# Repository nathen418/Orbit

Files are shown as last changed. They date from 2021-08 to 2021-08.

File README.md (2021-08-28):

# Orbit

# What happened here?
Old design files for an Arduino based clock I was building. Most stuff here is not mine, I was going to modify the files. Lost all of my work. This repo exists only so that I may return to the project at a later date. At the moment I have no energy or will to continue working on it as months of work has been lost. I got as far as fully working code and fully working hardware. I had the pcb's printed and soldered everything onto them. They worked perfectly. I still have all of the 8 revisions to the hardware. MONTHS of work gone, so 🤷‍♂️ I don't know what I am going to do. If I do return to the project, I will have to start from scratch, and will probably choose a Raspberry Pi Pico as the microcontroller, but I really have no idea.

Maybe in the future I will find a backup of the files and return to the project, however this seems unlikely.

Toodles.

## Questions?
- **Contact me on discord at nathen418#0002 or join my discord server at the link below**

## Modifications
- no issues will be resolved
- no pull requests wil be merged
- no comments on files will be answered.
- If you have a question, contact me through my discord

## Join my discord server:
https://dsc.gg/antaresnetwork

## License

- Im not a legal person so as long as I am credited in a somewhat obvious location, by my name or a link to this repository, I'm ok with it. If my name is not at the top of the file in a comment, it was not written by me and is only in this repo to serve as an example of something I was using for help. If my name does not appear on the file in a comment at the top, than it is not my code, it is class material.  If you have a problem with any of this, refer to my discord server and dm me.

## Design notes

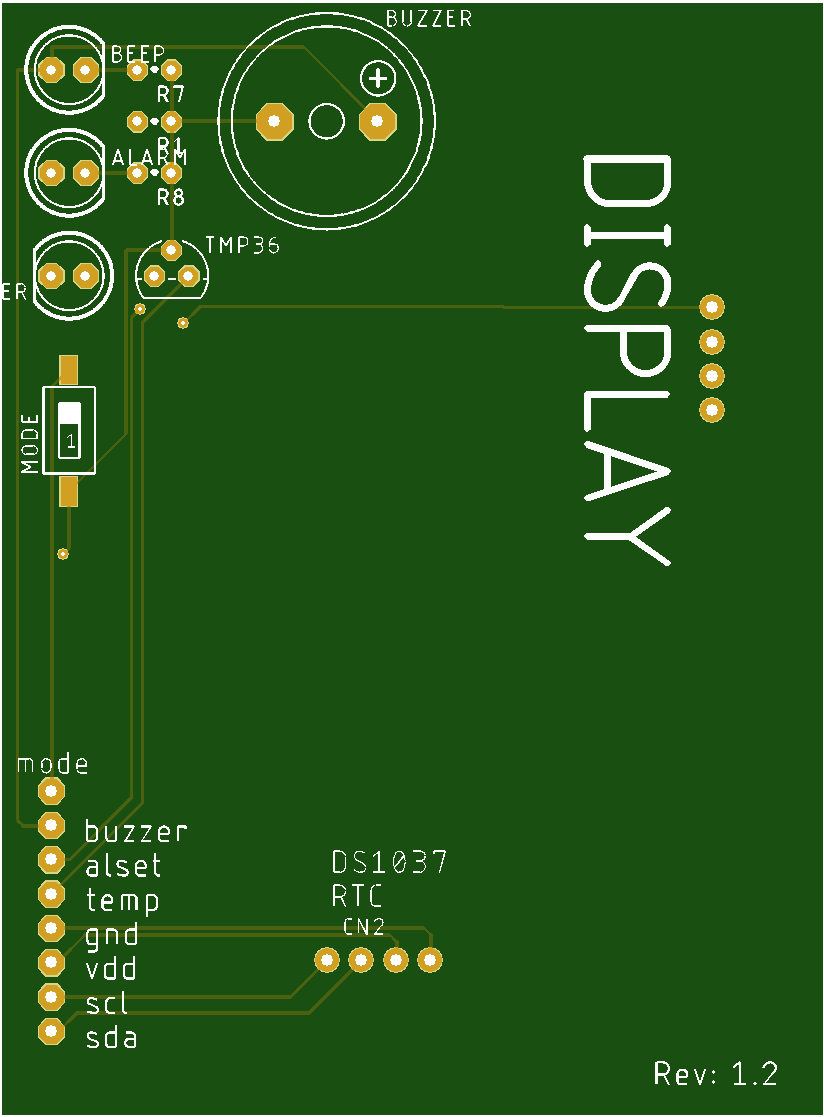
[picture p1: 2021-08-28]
downImg1.png

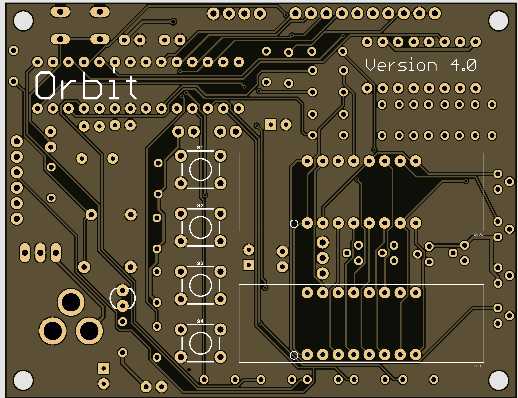
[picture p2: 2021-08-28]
Screenshot 2021-08-27 213251.png

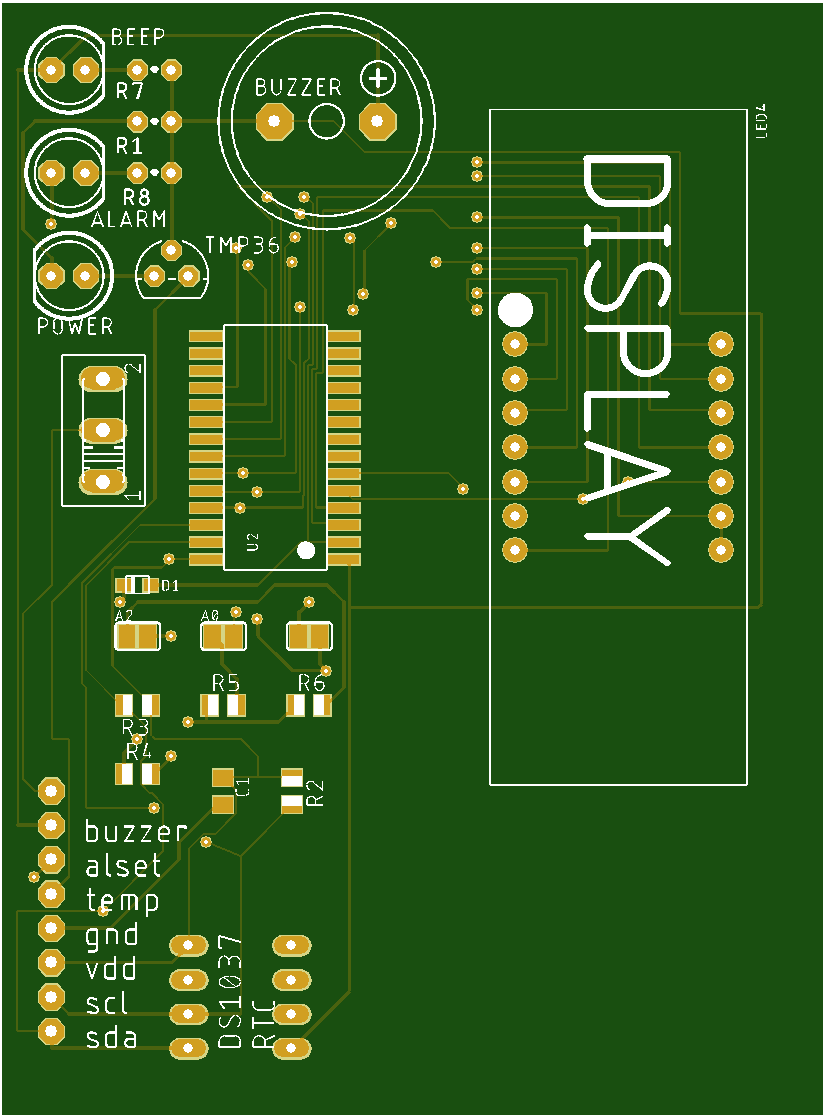
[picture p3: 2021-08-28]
downImg2.png

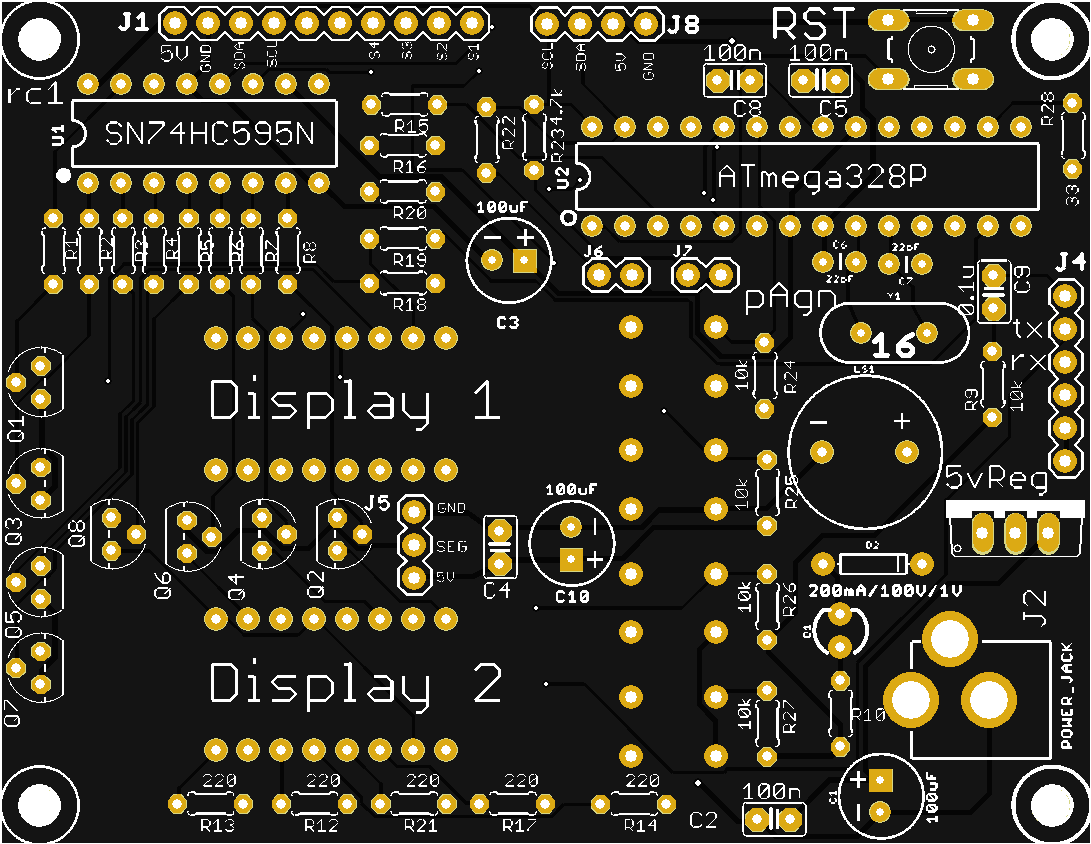
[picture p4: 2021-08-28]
downImg.png

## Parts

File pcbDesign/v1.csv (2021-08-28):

Qty | Value | Device | Package | Parts | Description
1 |  | 10-XX | B3F-10XX | RST | OMRON SWITCH
8 |  | 2N3906 | TO92 | Q1, Q2, Q3, Q4, Q5, Q6, Q7, Q8 | PNP Transistor
1 |  | 47346-0001 | MOLEX_47346-0001 | J3 | CONN RCPT 5POS MICRO USB R/A SMD
1 |  | 6_PIN_SERIAL_TARGET | 1X06 | J4 | 6-pin header connection for use with the FTDI BASIC" pinout - TARGET SIDE."
2 |  | CONN_02 | 1X02 | J6, J7 | Multi connection point. Often used as Generic Header-pin footprint for 0.1 inch spaced/style header connections
1 |  | CONN_03 | 1X03 | J5 | Multi connection point. Often used as Generic Header-pin footprint for 0.1 inch spaced/style header connections
1 |  | CONN_10";1X10" | J1 | Multi connection point. Often used as Generic Header-pin footprint for 0.1 inch spaced/style header connections
1 |  | I2C_STANDARD | 1X04 | J8 | SparkFun I2C Standard Pinout Header
1 |  | LED3MM | LED_3MM | D1 | LED (Generic)
4 |  | MOMENTARY-SWITCH-SPST-PTH-6.0MM | TACTILE_SWITCH_PTH_6.0MM | S1, S2, S3, S4 | Momentary Switch (Pushbutton) - SPST
1 | 0.1u | C-US025-025X050 | C025-025X050 | C9 | CAPACITOR, American symbol
4 | 100n | C-US025-025X050 | C025-025X050 | C2, C4, C5, C8 | CAPACITOR, American symbol
3 | 100uF | 100UF-POLAR-RADIAL-2.5MM-25V-20% | CPOL-RADIAL-2.5MM-6.5MM | C1, C3, C10 | 100µF polarized capacitors
5 | 10k | R-US_0204/5 | 0204/5 | R9, R24, R25, R26, R27 | RESISTOR, American symbol
1 | 16MHz | CRYSTAL-16MHZPTH-HC49US | HC49US | Y1 | 16MHz Crystal
1 | 1k | R-US_0204/5 | 0204/5 | R10 | RESISTOR, American symbol
1 | 200mA/100V/1V | DIODE-1N4148 | DIODE-1N4148 | D2 | Diode
10 | 220 | R-US_0204/5 | 0204/5 | R12, R13, R14, R15, R16, R17, R18, R19, R20, R21 | RESISTOR, American symbol
2 | 22pF | 22PF-PTH-2.54MM-200V-5% | CAP-PTH-2.54 | C6, C7 | 22pF ceramic capacitors
1 | 328P | ATMEGA328P_PDIP | DIP28 | U2 | Atmel 328P
1 | 33 | R-US_0204/5 | 0204/5 | R28 | RESISTOR, American symbol
8 | 330 | R-US_0204/5 | 0204/5 | R1, R2, R3, R4, R5, R6, R7, R8 | RESISTOR, American symbol
2 | 4.7k | R-US_0204/5 | 0204/5 | R22, R23 | RESISTOR, American symbol
1 | BUZZER-PTH | BUZZER-PTH | BUZZER-12MM | LS1 | Buzzer
1 | POWER_JACK | POWER_JACK | POWER_JACK_PTH | J2 | Power Jack Connector
1 | SN74HC595N | 74HC595N | DIP16 | U1 | 8-Bit Shift Register (Serial to Parallel)
2 | YSD-439AB4B-35 | 7-SEGMENT-4DIGIT-10MM-BLUE | 7-SEGMENT-4DIGIT-YOUNGSUN | LED1, LED2 | 4 Digit 7 Segment Display

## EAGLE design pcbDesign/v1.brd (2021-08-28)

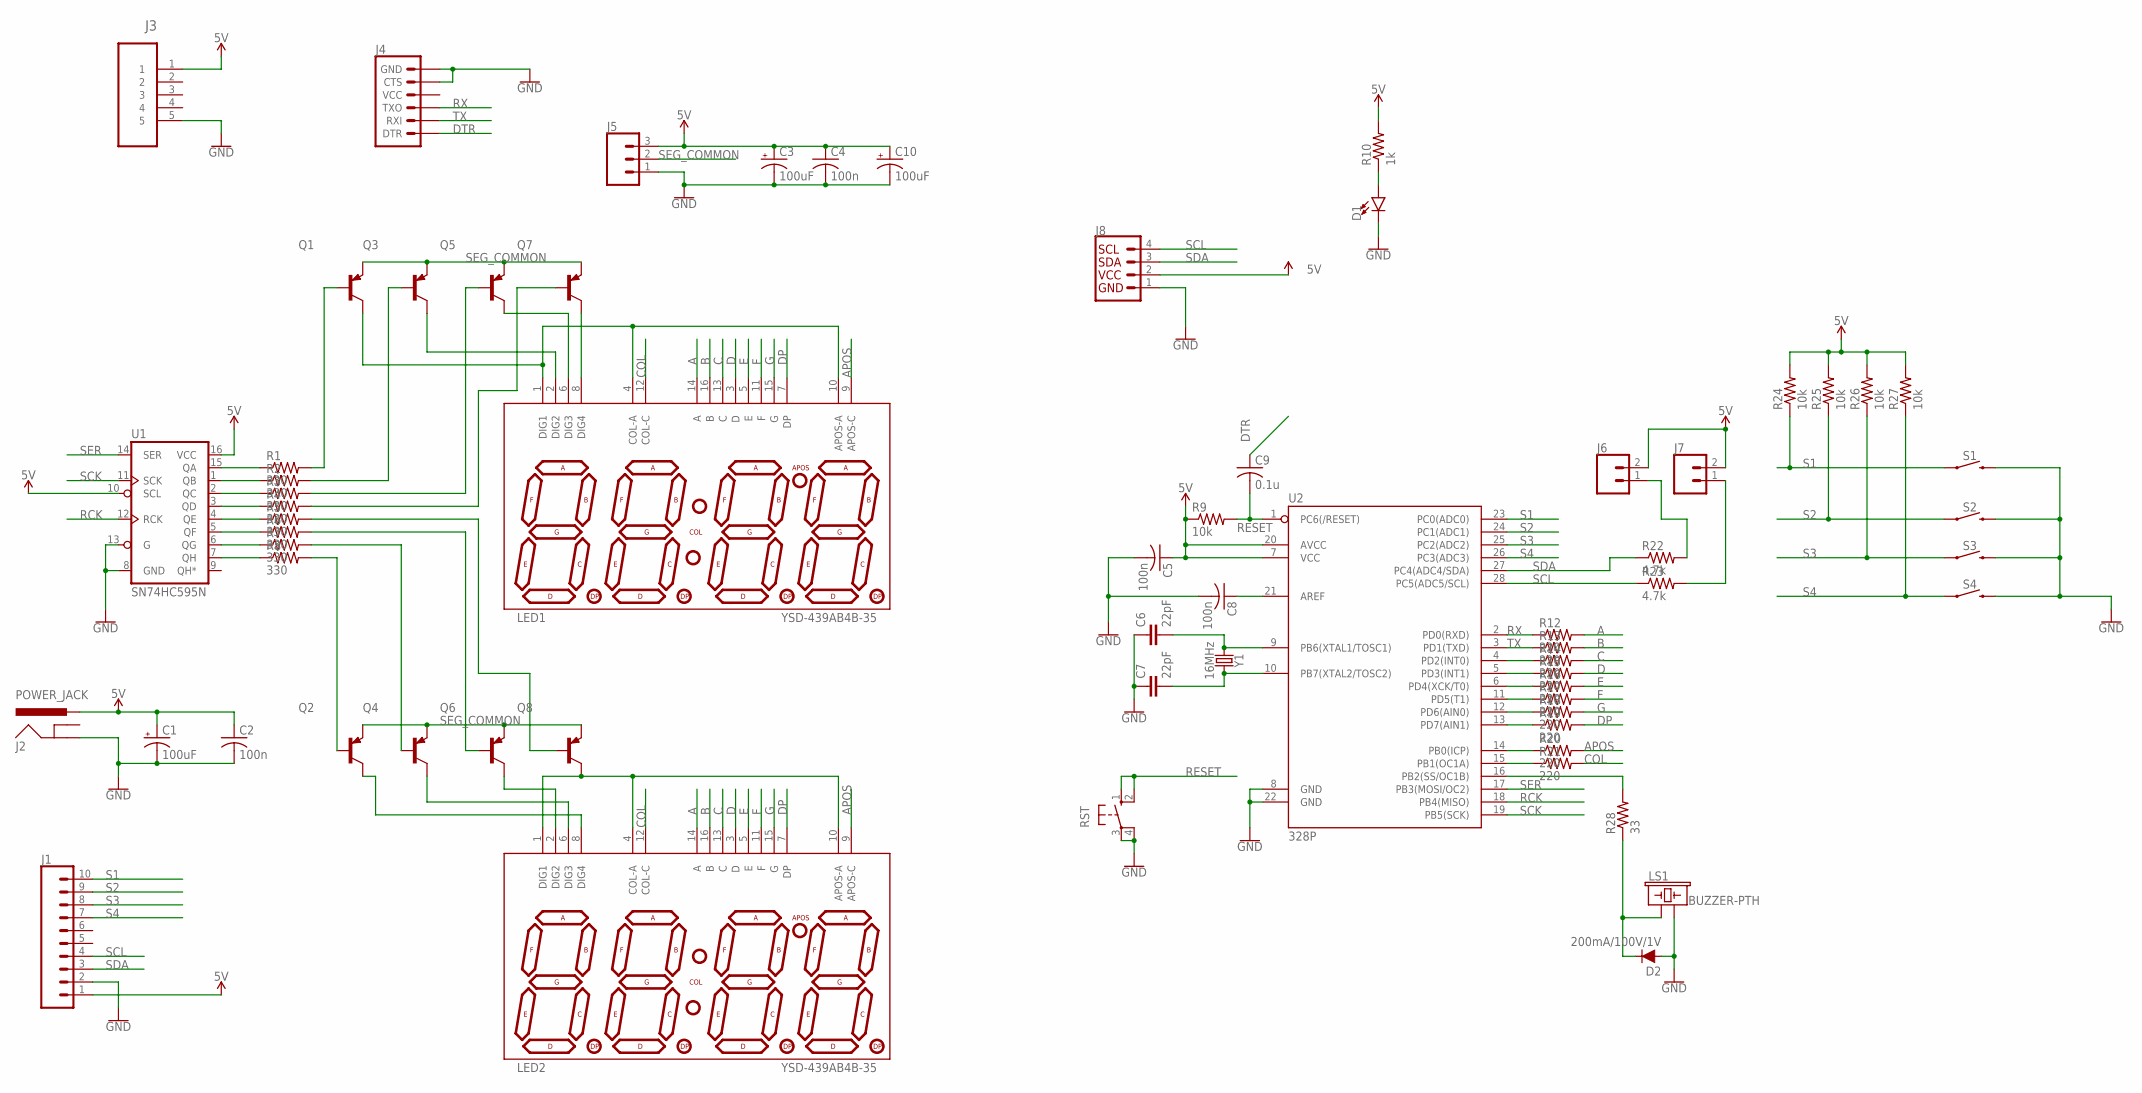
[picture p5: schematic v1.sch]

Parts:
C1, C3, C10: 100uF; CPOL-RADIAL-2.5MM-6.5MM
C2, C4, C5, C8: 100n; C025-025X050
C6, C7: 22pF; CAP-PTH-2.54
C9: 0.1u; C025-025X050
D1: LED3MM; LED_3MM
D2: 200mA/100V/1V; DIODE-1N4148
J1: CONN_10"; 1X10
J2: POWER_JACK; POWER_JACK_PTH
J3: 47346-0001; MOLEX_47346-0001
J4: 6_PIN_SERIAL_TARGET; 1X06
J5: CONN_03; 1X03
J6, J7: CONN_02; 1X02
J8: I2C_STANDARD; 1X04
LED1, LED2: YSD-439AB4B-35; 7-SEGMENT-4DIGIT-YOUNGSUN
LS1: BUZZER-PTH; BUZZER-12MM
Q1, Q2, Q3, Q4, Q5, Q6, Q7, Q8: 2N3906; TO92
R1, R2, R3, R4, R5, R6, R7, R8: 330; 0204/5
R9, R24, R25, R26, R27: 10k; 0204/5
R10: 1k; 0204/5
R12, R13, R14, R15, R16, R17, R18, R19, R20, R21: 220; 0204/5
R22, R23: 4.7k; 0204/5
R28: 33; 0204/5
RST: 10-XX; B3F-10XX
S1, S2, S3, S4: MOMENTARY-SWITCH-SPST-PTH-6.0MM; TACTILE_SWITCH_PTH_6.0MM
U1: SN74HC595N; DIP16
U2: 328P; DIP28
Y1: 16MHz; HC49US

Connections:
5V: C1.1 (+), C2.1, C3.1 (+), C4.1, C5.1, C10.1 (+), J1.1, J2.PWR, J3.1, J5.3, J6.2, J7.2, J8.2, R9.1, R10.2, R24.2, R25.2, R26.2, R27.2, U1.10 (SCL), U1.16 (VCC), U2.7 (VCC), U2.20 (AVCC)
A: LED1.14 (A), LED2.14 (A), R12.2
APOS: LED1.9 (APOS-C), LED2.9 (APOS-C), R20.2
B: LED1.16 (B), LED2.16 (B), R13.2
C: LED1.13 (C), LED2.13 (C), R14.2
COL: LED1.12 (COL-C), LED2.12 (COL-C), R21.2
D: LED1.3 (D), LED2.3 (D), R15.2
DP: LED1.7 (DP), LED2.7 (DP), R19.2
DTR: C9.1, J4.1 (DTR)
E: LED1.5 (E), LED2.5 (E), R16.2
F: LED1.11 (F), LED2.11 (F), R17.2
G: LED1.15 (G), LED2.15 (G), R18.2
GND: C1.2 (-), C2.2, C3.2 (-), C4.2, C5.2, C6.1, C7.1, C8.2, C10.2 (-), D1.K (C), D2.A, J1.2, J2.GND, J3.5, J4.5 (CTS), J4.6 (GND), J5.1, J8.1, LS1.- (2), RST.3, RST.4 (P1), S1.3 (2), S2.3 (2), S3.3 (2), S4.3 (2), U1.8 (GND), U1.13 (G), U2.8 (GND), U2.22 (GND)
unnamed: D1.A, R10.1
unnamed: R21.1, U2.15 (PB1(OC1A))
unnamed: R14.1, U2.4 (PD2(INT0))
unnamed: R15.1, U2.5 (PD3(INT1))
unnamed: R16.1, U2.6 (PD4(XCK/T0))
unnamed: R17.1, U2.11 (PD5(T1))
unnamed: R18.1, U2.12 (PD6(AIN0))
unnamed: R19.1, U2.13 (PD7(AIN1))
unnamed: C6.2, U2.9 (PB6(XTAL1/TOSC1)), Y1.1
unnamed: C7.2, U2.10 (PB7(XTAL2/TOSC2)), Y1.2
unnamed: LED1.1 (DIG1), LED1.4 (COL-A), LED1.10 (APOS-A), Q1.1 (C)
unnamed: LED1.6 (DIG3), Q5.1 (C)
unnamed: LED1.2 (DIG2), Q3.1 (C)
unnamed: R28.2, U2.16 (PB2(SS/OC1B))
unnamed: LED2.1 (DIG1), LED2.4 (COL-A), LED2.10 (APOS-A), Q8.1 (C)
unnamed: D2.C, LS1.+ (1), R28.1
unnamed: LED2.2 (DIG2), Q6.1 (C)
unnamed: LED2.6 (DIG3), Q4.1 (C)
unnamed: LED2.8 (DIG4), Q2.1 (C)
unnamed: LED1.8 (DIG4), Q7.1 (C)
unnamed: Q1.2 (B), R1.2
unnamed: Q3.2 (B), R2.2
unnamed: Q5.2 (B), R3.2
unnamed: Q7.2 (B), R4.2
unnamed: Q8.2 (B), R5.2
unnamed: Q6.2 (B), R6.2
unnamed: Q4.2 (B), R7.2
unnamed: Q2.2 (B), R8.2
unnamed: R1.1, U1.15 (QA)
unnamed: R2.1, U1.1 (QB)
unnamed: R3.1, U1.2 (QC)
unnamed: R4.1, U1.3 (QD)
unnamed: R5.1, U1.4 (QE)
unnamed: R6.1, U1.5 (QF)
unnamed: R7.1, U1.6 (QG)
unnamed: R8.1, U1.7 (QH)
unnamed: C8.1, U2.21 (AREF)
unnamed: J6.1, R22.2
unnamed: J7.1, R23.2
unnamed: R20.1, U2.14 (PB0(ICP))
RCK: U1.12 (RCK), U2.18 (PB4(MISO))
RESET: C9.2, R9.2, RST.1 (S), RST.2 (S1), U2.1 (PC6(/RESET))
RX: J4.3 (TXO), R12.1, U2.2 (PD0(RXD))
S1: J1.10, R24.1, S1.1, U2.23 (PC0(ADC0))
S2: J1.9, R25.1, S2.1, U2.24 (PC1(ADC1))
S3: J1.8, R26.1, S3.1, U2.25 (PC2(ADC2))
S4: J1.7, R27.1, S4.1, U2.26 (PC3(ADC3))
SCK: U1.11 (SCK), U2.19 (PB5(SCK))
SCL: J1.4, J8.4, R23.1, U2.28 (PC5(ADC5/SCL))
SDA: J1.3, J8.3, R22.1, U2.27 (PC4(ADC4/SDA))
SEG_COMMON: J5.2, Q1.3 (E), Q2.3 (E), Q3.3 (E), Q4.3 (E), Q5.3 (E), Q6.3 (E), Q7.3 (E), Q8.3 (E)
SER: U1.14 (SER), U2.17 (PB3(MOSI/OC2))
TX: J4.2 (RXI), R13.1, U2.3 (PD1(TXD))

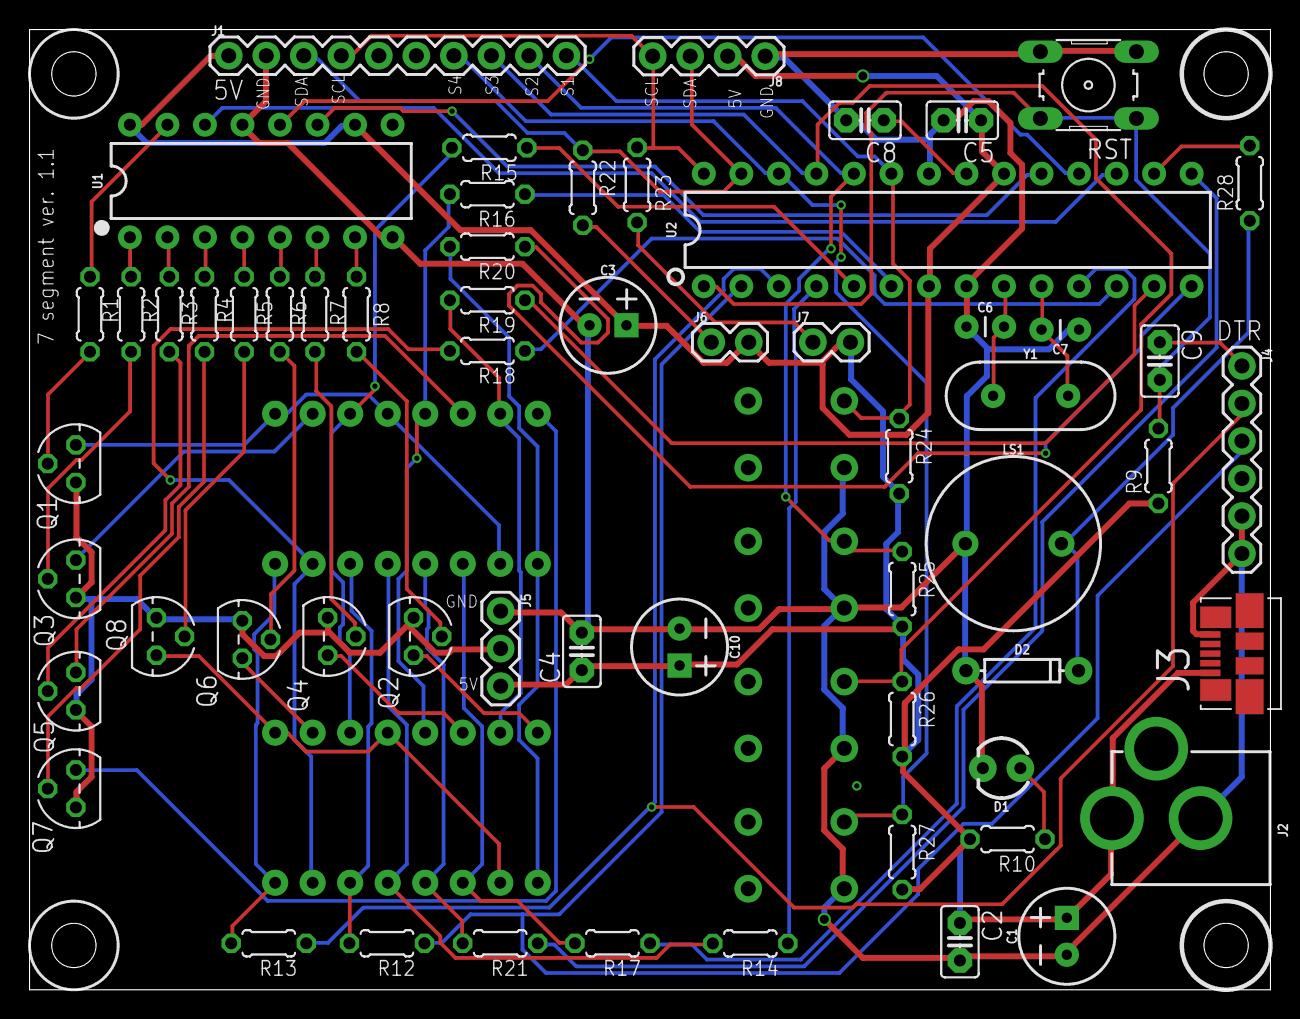
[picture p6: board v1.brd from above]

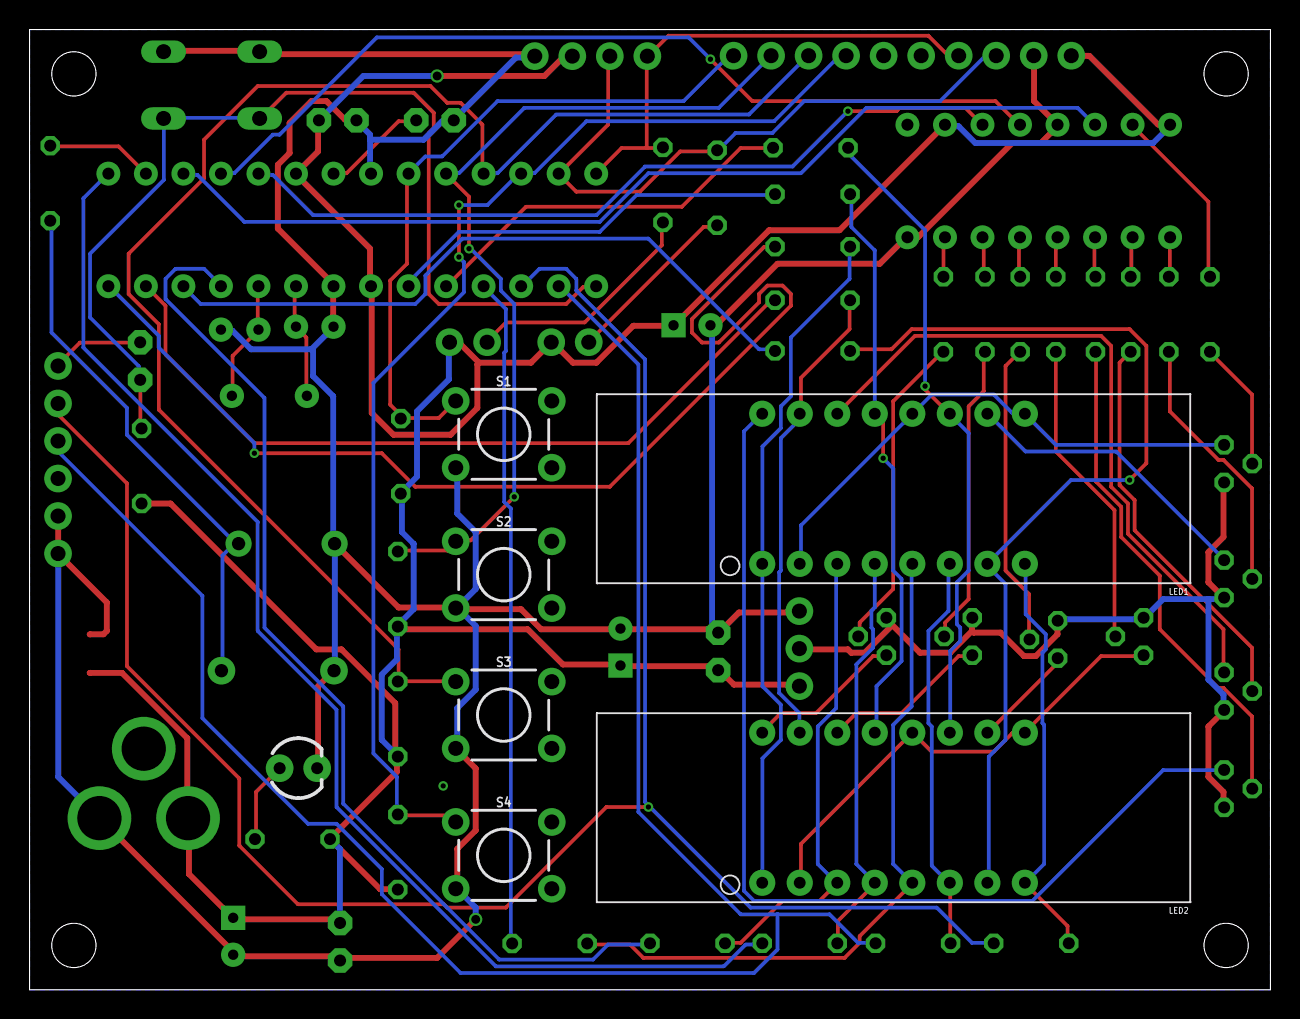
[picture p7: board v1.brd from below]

Board: 2 copper layers, 84.0 x 65.0 mm, 66 parts (6 on the bottom side), 66 nets.

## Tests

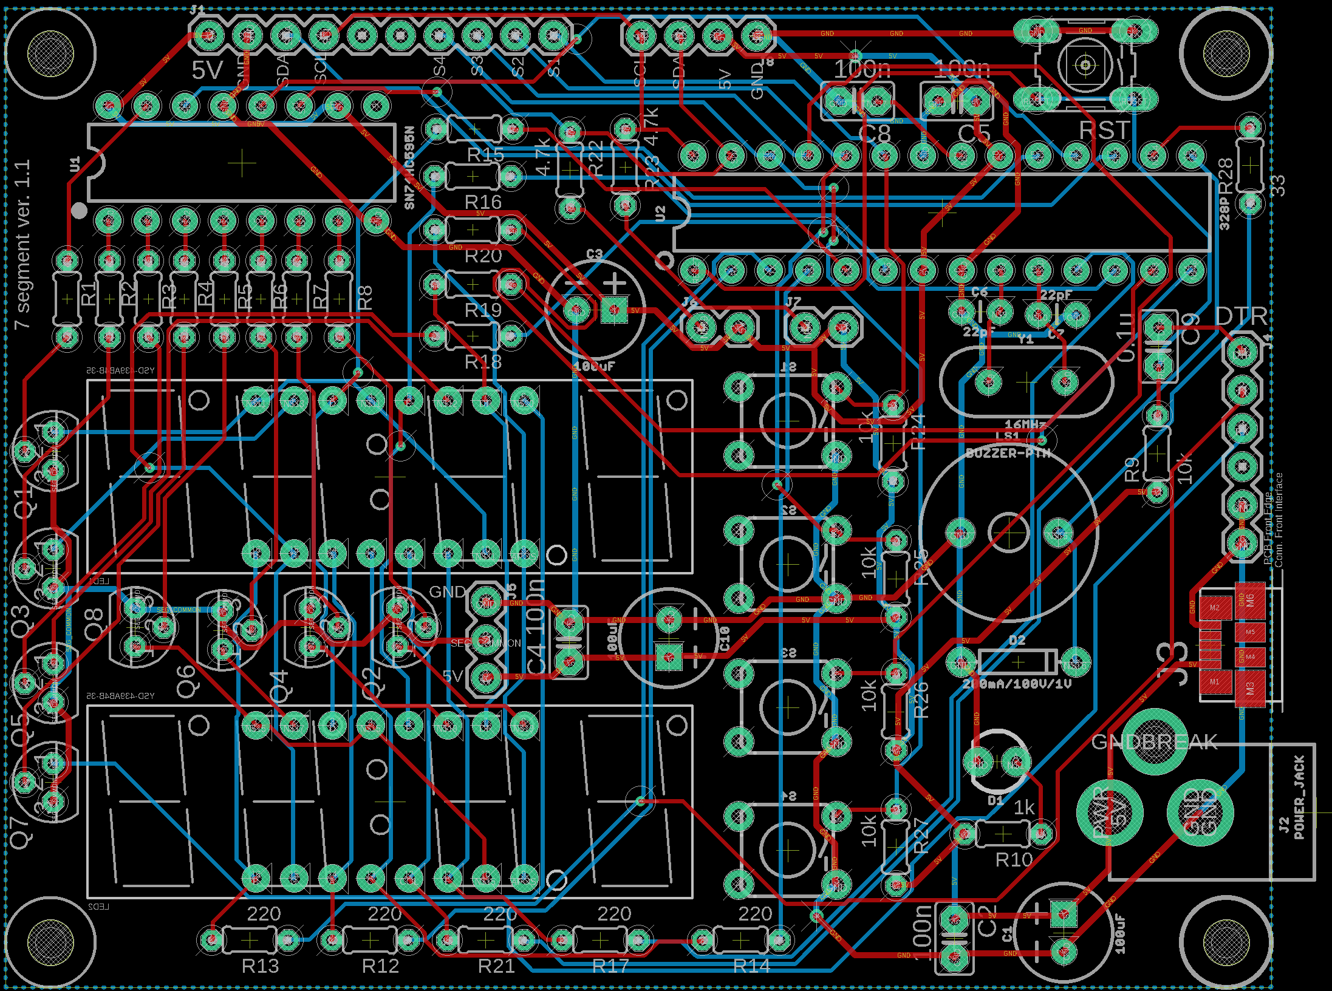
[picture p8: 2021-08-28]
pcbDesign/testshot2.png

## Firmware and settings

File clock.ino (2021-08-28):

//Global libraries
#include <TimeLib.h>  
#include <Wire.h>
#include <RTClib.h>
#include <PinChangeInterrupt.h>
//Local libraries
#include "sevenseg_display_drv.h"

//Define section
#define BUTTON_PLUS 12
#define BUTTON_MINUS 11
#define BUTTON_MODE 10
#define BUTTON_SET 13
#define MAX_MODE 2
#define SECS_PER_HOUR 3600


//Top variables
sevenseg_display_drv display7seg;
double light;
volatile uint8_t mode,stopwatch_running,mode_button_pressed;
volatile unsigned long last_time_button_falling,last_time_button_rising,elapsed_millisec,stopwatch_start_millisec;
//unsigned long 

RTC_DS3231 rtc;

void loop(){
	switch (mode) {
		case 0:
			mode=1;
			display7seg.clear_all();
			display7seg.set_dp_bottom(2);
			break;
		case 1://Clock with date
			show_clock_up();
			show_date_down();
			set_brightness();
			break;
		case 10://Clock with year
			display7seg.clear_all();
			mode=11;
			break;
		case 11://Clock with year
			show_clock_up();
			show_year_down();
			set_brightness();
			break;
		case 20://Stop watch
			mode=21;
			display7seg.clear_all();
			display7seg.set_colon_top();
			display7seg.set_dp_bottom(2);
			break;
		case 21://Stop watch
			stopwatch();
			break;
		default:
			mode=0;
			break;
	}//switch
}

void stopwatch(){
	//Stopwatch function	
	if(stopwatch_running==1) elapsed_millisec=millis()-stopwatch_start_millisec;
	
	uint16_t total_sec=elapsed_millisec/1000;
	uint16_t delata_millisec=elapsed_millisec%1000;
	uint8_t delta_sec=total_sec%60;
	uint8_t delta_min=total_sec/60%60;
	uint8_t delta_hour=total_sec/60/60;
	
	uint8_t digit;
	digit=elapsed_millisec/10%10;
	display7seg.set_digit_bottom(0, digit);
	digit=elapsed_millisec/100%10;
	display7seg.set_digit_bottom(1, digit);
	digit=delta_sec%10;
	display7seg.set_digit_bottom(2, digit);
	digit=delta_sec/10;
	display7seg.set_digit_bottom(3, digit);
	
	digit=delta_min%10;
	display7seg.set_digit_top(0, digit);
	digit=delta_min/10;
	display7seg.set_digit_top(1, digit);
	digit=delta_hour%10;
	display7seg.set_digit_top(2, digit);
	digit=delta_hour/10;
	display7seg.set_digit_top(3, digit);
}

void set_brightness(){
	light = 0;
	for (int i = 0; i < 2000; i++) {
		light += analogRead(A3);
	}

	light = int((light/ 2000) / 1024 * 15);
	display7seg.set_brightness(light);
}

void show_clock_up(){
	display7seg.set_digit_top(0, minute()%10);
	display7seg.set_digit_top(1, minute()/10);
	display7seg.set_digit_top(2, hour()%10);
	display7seg.set_digit_top(3, hour()/10);
	
	if (millis()%1000 > 500) display7seg.set_colon_top();
	else display7seg.reset_colon_top();
}

void show_date_down(){
	display7seg.set_digit_bottom(0, month()%10);
	display7seg.set_digit_bottom(1, month()/10);
	display7seg.set_digit_bottom(2, day()%10);
	display7seg.set_digit_bottom(3, day()/10);
}

void show_year_down(){
	uint8_t digit;
	
	digit=year()%10;
	display7seg.set_digit_bottom(0, digit);
	digit=year()/10%10;
	display7seg.set_digit_bottom(1, digit);
	digit=year()/100%10;
	display7seg.set_digit_bottom(2, digit);
	digit=year()/1000%10;
	display7seg.set_digit_bottom(3, digit);
}

void print_float_num_bottom(double floatnum) {
	char tempString[5];
	int fourdigits;

	display7seg.reset_dp_bottom(0);
	display7seg.reset_dp_bottom(1);
	display7seg.reset_dp_bottom(2);
	display7seg.reset_dp_bottom(3);
	
	int dig_num = log10(floatnum) + 1;
	if (dig_num >= 0) {
		fourdigits = round(floatnum*pow(10, 4 - dig_num));
		if (fourdigits==0) sprintf(tempString, "%4s", "0000");
		else sprintf(tempString, "%4d", fourdigits);
		display7seg.set_digit_bottom(0, (uint8_t)(tempString[3] - '0'));
		display7seg.set_digit_bottom(1, (uint8_t)(tempString[2] - '0'));
		display7seg.set_digit_bottom(2, (uint8_t)(tempString[1] - '0'));
		display7seg.set_digit_bottom(3, (uint8_t)(tempString[0] - '0'));
		display7seg.set_dp_bottom(4 - dig_num);
	}
	else {
		fourdigits = round(floatnum*10000);
		sprintf(tempString, "%4d", fourdigits);
		display7seg.set_digit_bottom(0, fourdigits % 10 );
		display7seg.set_digit_bottom(1, fourdigits /10 %10);
		display7seg.set_digit_bottom(2, (fourdigits /100 % 10));
		display7seg.set_digit_bottom(3, 0);
		display7seg.set_dp_bottom(3);
	}
}

//http://forum.arduino.cc/index.php?topic=44262.0
char *ftoa(char *a, double f, int precision)
{
	long p[] = { 0,10,100,1000,10000,100000,1000000,10000000,100000000 };

	char *ret = a;
	long heiltal = (long)f;
	itoa(heiltal, a, 10);
	while (*a != '\0') a++;
	*a++ = '.';
	long desimal = abs((long)((f - heiltal) * p[precision]));
	itoa(desimal, a, 10);
	return ret;
}

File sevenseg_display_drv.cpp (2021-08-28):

#include "sevenseg_display_drv.h"

static sevenseg_display_drv *active7segment = NULL;

sevenseg_display_drv::sevenseg_display_drv() { }

void sevenseg_display_drv::begin_drv()
{
	//Start refreshing Nothing will be displayed before this function called
	//From http://www.instructables.com/id/Arduino-Timer-Interrupts/
	//Set timer1 - 16 bit timer
	
	cli();// disable global interrupts
	TCCR1A = 0;// set entire TCCR1A register to 0
	TCCR1B = 0;// same for TCCR1B
	TCNT1 = 0;//initialize counter value to 0

	//Prescaller (timer speed(Hz)) = (Arduino clock speed(16MHz)) / prescaler
	TCCR1B |= (1 << CS10); //No prescaller 63ns per count for 16MHz clock
	
	//Also notice how the setups between the three timers differ slightly in the line which turns on CTC mode :
	//TCCR0A |= (1 << WGM01);//for timer0
	//TCCR1B |= (1 << WGM12);//for timer1
	//TCCR2A |= (1 << WGM21);//for timer2
	TCCR1B |= (1 << WGM12);//CTC mode

	// OCR#A (the compare match value)
	//remember that when you use timers 0 and 2 this number must be less than 256, and less than 65536 for timer1
	OCR1A = 999;//intrupt will happen 63ns*[this value] 63usec for 999
	//OCR1A = 496;//31usec
	TIMSK1 |= (1 << OCIE1A); // enable timer compare interrupt
	sei();//allow interrupts
}

ISR(TIMER1_COMPA_vect) {//change the 1 to 0 for timer0 and 2 for timer2
	active7segment->updateDisplay();//Matrix refrshing function
}

uint8_t sevenseg_display_drv::init()
{
	//Initialisation
	DDRB |= B00000011;//Set pins 0,1 of port B as output
	DDRD |= B11111111;//Sets pins 0 to 7 of port D as outputs, segments control
	DDRC |= B00000111;//Set bits 0,1,2 of port C as output, connection to 74HC595N


	PORTB &= B11111100;//Turn off colon and apostrof
	PORTD =  B00000000;//Turn off all segments
	PORTC &= B11111000;//Shift register controls low
	
	//Clear all bits of shift register
	for (uint8_t n = 0; n < NUMOFDIGITS; n++) {
		PORTC |= B00000010;//Serial clock high
		PORTC &= B11111101;//Serial clock low
	}
	PORTC |= B00000100;//Latch shift register data

	active7segment = this; // For interrupt hander

	//Clear memory
	clear_all();

	//For pwm_count_max=15 each digit can be turn on up to 1ms out of 8 ms
	//So reftesh rate something like 125Hz
	//pwm_count_max = 15;//Number of brightness levels
	brightness = 15;//Default value of brightness

	//Initiate variables
	pwm_count = 0;
	digit_num = 0;
	return 0;
}

void sevenseg_display_drv::clear_all(){
	//Clear memory
	for (uint8_t n = 0; n < NUMOFDIGITS; n++) {
		dp_buffer[n] =   B00000000;//Reset decimal point buffer
		displaybuff[n] = B00000000;//Set all digits to off
		colon_and_ap[n]= B00000000;//Clean colon and apos
	}
}

void sevenseg_display_drv::clear_top(){
	//Clear memory
	for (uint8_t n = 4; n < NUMOFDIGITS; n++) {
		dp_buffer[n] =   B00000000;//Reset decimal point buffer
		displaybuff[n] = B00000000;//Set all digits to off
		colon_and_ap[n]= B00000000;//Clean colon and apos
	}
}

void sevenseg_display_drv::clear_bottom(){
	//Clear memory
	for (uint8_t n = 0; n < 4; n++) {
		dp_buffer[n] =   B00000000;//Reset decimal point buffer
		displaybuff[n] = B00000000;//Set all digits to off
		colon_and_ap[n]= B00000000;//Clean colon and apos
	}
}

void sevenseg_display_drv::updateDisplay()
{
	/*
	This function refreshing display. Called only from interupt
	*/
	
	//Debug
	//PORTC |= B00000001;//Turn off all digits

	if (pwm_count < PWMCOUNTMAX) {
		//For brightness=0 display will be on for 1 cycle
		if (pwm_count > brightness) {
			PORTB &= B11111100;//Turn off colon and apostrof
			PORTD =  B00000000;//Turn off all segments
		}
		pwm_count++;//PWM counter
	}
	else {//End of current pwm cycle
		//Here we need to update information of digit
		pwm_count = 0;//restart pwm counter
		//Turn off all
		PORTB &= B11111100;//Turn off colon and apostrof
		PORTD  = B00000000;//Turn off all segments

		if (digit_num < NUMOFDIGITS) {// Digits 1-7
			PORTC &= B11111000;//Shift register latch data and clock signal low
			PORTC |= B00000010;//Serial clock high
			PORTC |= B00000101;//Latch data, serial data to high
		}
		else {//Digit 0
			digit_num = 0;//First digit
			//Turn on first digit
			PORTC &= B11111001;//Shift register latch and clock signal low. Data already high vrom previous cycle
			PORTC |= B00000010;//Serial clock high
			PORTC |= B00000100;//Latch data
		}
		//Ser digit data
		PORTD = displaybuff[digit_num];//Apply data for segments of current digit
		PORTB |= colon_and_ap[digit_num];//Colon and apostrophe 
		digit_num++;//Next digit
	}//end else
	
	//*** Debug ***
	//long elapsed = micros() - time_start;
	//Serial.println(elapsed);
	//PORTC &= B11111110;//Turn off all digits
	//********************
}

//Set value of digit
void sevenseg_display_drv::set_digit( uint8_t dig_num, uint8_t value){
	if(dig_num<0 || dig_num>(NUMOFDIGITS-1)) return;
	displaybuff[dig_num]=pgm_read_byte_near(&bcd[value])|dp_buffer[dig_num];
}

void sevenseg_display_drv::set_digit_top( uint8_t dig_num, uint8_t value){
	set_digit( dig_num+4, value);
}

void sevenseg_display_drv::set_digit_bottom( uint8_t dig_num, uint8_t value){
	set_digit( 3-dig_num, value);
}

//Set brightness of all digits
void sevenseg_display_drv::set_brightness(uint8_t value) {
	if (value<= PWMCOUNTMAX) brightness = value;
	else brightness = PWMCOUNTMAX;
}


void sevenseg_display_drv::set_dp_top(uint8_t dig_num) {
	if(dig_num<0 || dig_num>(NUMOFDIGITS-1)) return;
	dp_buffer[dig_num+4] = B10000000;
	displaybuff[dig_num+4] |= dp_buffer[dig_num+4];
}

void sevenseg_display_drv::set_dp_bottom(uint8_t dig_num) {
	if(dig_num<0 || dig_num>(NUMOFDIGITS-1)) return;
	dp_buffer[3-dig_num] = B10000000;
	displaybuff[3-dig_num] |= dp_buffer[3-dig_num];
}

void sevenseg_display_drv::reset_dp_top(uint8_t dig_num) {
	if(dig_num<0 || dig_num>(NUMOFDIGITS-1)) return;
	dp_buffer[dig_num] = B00000000;
	displaybuff[dig_num] &= B01111111;
}

void sevenseg_display_drv::reset_dp_bottom(uint8_t dig_num) {
	if(dig_num<0 || dig_num>(NUMOFDIGITS-1)) return;
	dp_buffer[dig_num] = B00000000;
	displaybuff[dig_num] &= B01111111;
}

void sevenseg_display_drv::set_colon_top() {
	for (uint8_t n = 4; n < 8; n++) {
		colon_and_ap[n] |=B00000010;
	}
}

void sevenseg_display_drv::set_colon_bottom() {
	for (uint8_t n = 0; n < 4; n++) {
		colon_and_ap[n] |=B00000010;
	}
}

void sevenseg_display_drv::reset_colon_top() {
	for (uint8_t n = 4; n < 8; n++) {
		colon_and_ap[n] &=B11111101;
	}
}

void sevenseg_display_drv::reset_colon_bottom() {
	for (uint8_t n = 0; n < 4; n++) {
		colon_and_ap[n] &=B11111101;
	}
}

void sevenseg_display_drv::set_apostrophe_top() {
	for (uint8_t n = 4; n < 8; n++) {
		
	}
}

void sevenseg_display_drv::set_apostrophe_bottom() {
	for (uint8_t n = 0; n < 4; n++) {
		
	}
}

void sevenseg_display_drv::reset_apostrophe_top() {
	for (uint8_t n = 4; n < 8; n++) {
		
	}
}

void sevenseg_display_drv::reset_apostrophe_bottom() {
	for (uint8_t n = 0; n < 4; n++) {
		
	}
}

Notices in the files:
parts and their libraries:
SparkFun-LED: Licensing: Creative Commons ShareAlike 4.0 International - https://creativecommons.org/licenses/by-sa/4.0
